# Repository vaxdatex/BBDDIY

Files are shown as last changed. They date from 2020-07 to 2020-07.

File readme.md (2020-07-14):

As Erica Synths discontinues its legacy DIY eurorack projects, we decided to make them open-source. We created Gerber files for PCB-made front panels and did slight changes in a module design in order to get rid of custom and rare components, still some modules require rare ICs which are available on www.ericasynths.lv. Each folder contains complete information and files to build a module: schematics, Gerber files for a front panel, Gerber files for PCBs, BOMs, component placement with values and designators and assembly manuals (please, note that some manuals are designed for older module versions). By making these projects opensource, Erica Synths is ok, if the third parties use them for personal, educational or commercial purposes. Erica Synths will not provide any support for these projects, please, refer to forums (www.muffwiggler.com) for information on build nuances, troubleshooting, part availability or alternatives.

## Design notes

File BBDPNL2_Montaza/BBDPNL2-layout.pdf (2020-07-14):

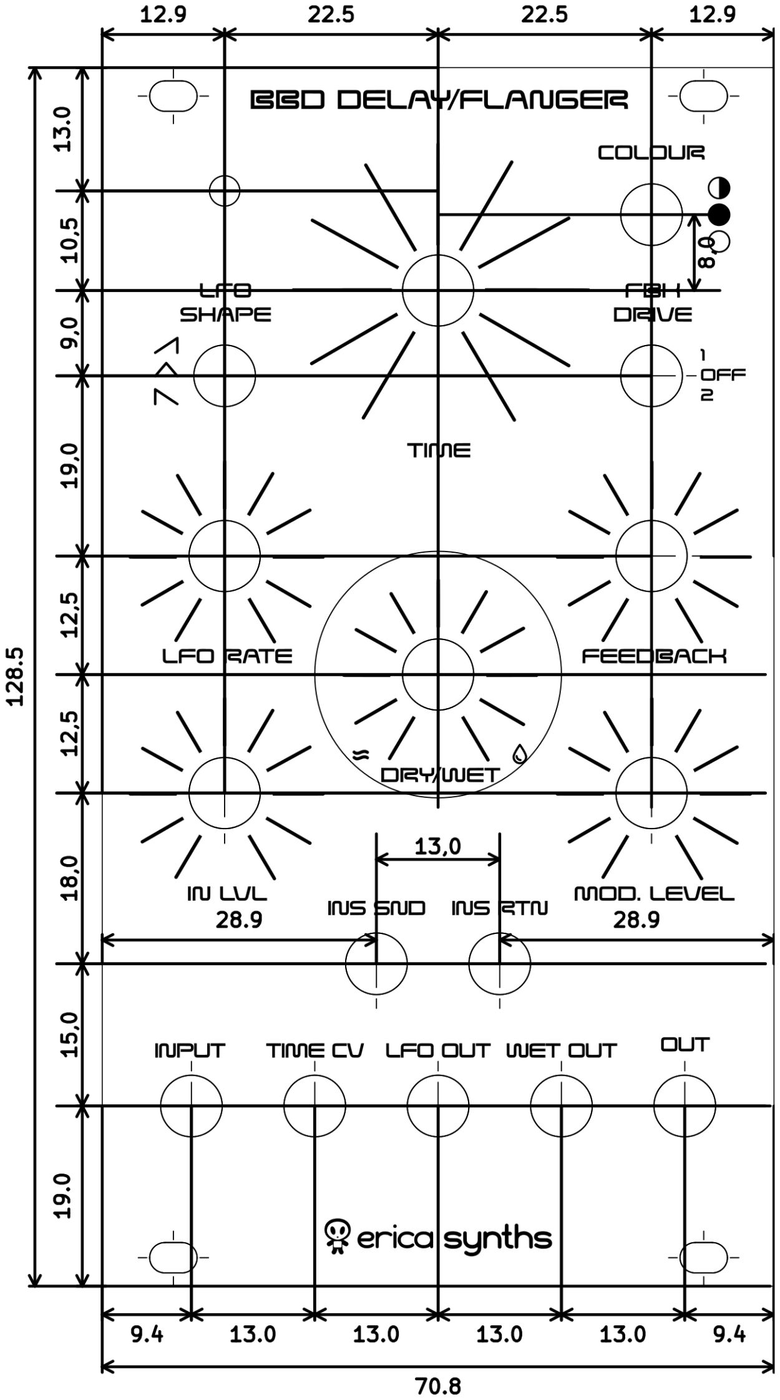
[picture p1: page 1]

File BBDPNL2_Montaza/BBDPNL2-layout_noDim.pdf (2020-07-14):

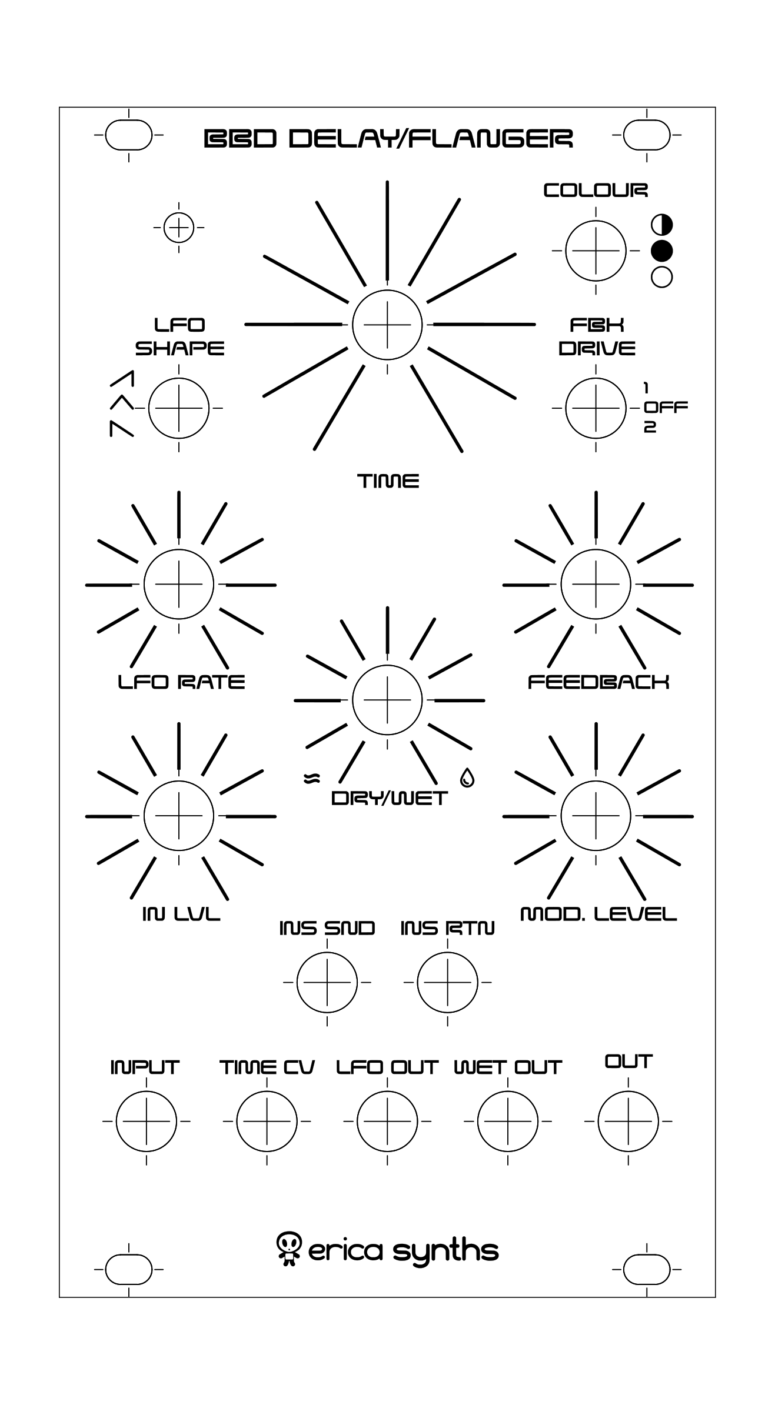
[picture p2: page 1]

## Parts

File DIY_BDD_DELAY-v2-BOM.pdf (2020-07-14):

Id Designator | Package | Quantity Designation | Supplier and ref
1 C7,C8,C11,C14,C16,C23,C25,C31,C35 | C-5mm | 9 | 0.1uF
2 C12 | CE63x25 | 1 | 10uFx25V
3 DA2 | DIP-14 | 1 | TL074
4 DA4 | DIP-14 | 1 | CD4011BE
5 DA5 | TO-92 | 1 | LM317L
6 DD1 | DIP-14 | 1 | V3205SD/MN3205 | comes with a kit
7 DD2 | DIP-8 | 1 | V3102/MN3102 | comes with a kit
8 R7 | RKT6V | 1 | 10k | single turn trimpot
9 R8 | RKT6V | 1 | 100k | single turn trimpot
10 VT1,VT2 | TO-92-M | 2 | 2N3904
11 C15 | CE63x25 | 1 | 22uFx25V
12 C19 | C-5mm | 1 | 2.2nF
13 C20,C34 | C-5mm | 2 | 1.0nF
14 C21,C29,C30 | CE63x25 | 3 | 3.3uFx16V
15 C36 | C-5mm | 1 | 220pF
16 C37 | C-5mm | 1 | 47pF
17 VD22,VD23,VD24,VD29,VD30 | DO-35 | 5 | 1N4148
18 XP2,XP3 | PLS-10 | 2 | PLS-10_MALE | comes with a kit
19 R10 | R_W4_THT | 1 | 3.9k
20 R11,R21,R39,R42,R49 | R_W4_THT | 5 | 100k
21 R13 | R_W4_THT | 1 | 8.2k
22 R14,R38,R41,R70 | R_W4_THT | 4 | 5.6k
23 R15,R16,R22 | R_W4_THT | 3 | 15k
24 R17 | R_W4_THT | 1 | 1k
25 R18 | R_W4_THT | 1 | 22k
26 R47,R66,R75,R77 | R_W4_THT | 4 | 3.3k
27 R48,R51,R55,R58,R65 | R_W4_THT | 5 | 33k
28 R54,R61,R76 | R_W4_THT | 3 | 56k
29 R62 | R_W4_THT | 1 | 2.2k
30 R63,R64 | R_W4_THT | 2 | NU | not used
31 R69 | R_W4_THT | 1 | 560ohm
31 DA1, DA4, DD1 | DIP-14 | 3 | DIP-14 Socket
31 DD2 | DIP-8 | 1 | DIP-8 Socket
PCB: DIYBBD1M

Erica Synths DIY BBD DELAY Main Board
v2.0 Sept. 2018

Id Designator | Package | Quantity Designation | Supplier and ref
1 C1,C2 | CE63x25 | 2 | 47uFx25V
2 C3,C4,C5,C6,C9,C10 | C-5mm | 6 | 0.1uF
3 DA1 | DIP-14 | 1 | TL074
4 DA3 | DIP-8 | 1 | TL072
5 L1,L2 | R0125W | 2 | 100uH | ferrite bead
6 R1,R3,R4,R6 | RD901F | 4 | B100k | Alpha potentiometer
7 R5 | RD901F | 1 | A100k | Alpha potentiometer
8 R2 | RD901F | 1 | B250k | Alpha potentiometer
9 SW1,SW2 | 2MSxT1B5M2RE | 2 | 2MS3T1B5M2RE | SPDT On-Off-On switch (https://www.thonk.co.uk/shop/sub-mini-toggle-switches/)
10 VD1 | LED-3MM | 1 | LED-3mm | Yellow LED
11 VD7,VD10 | LED-3MM | 2 | LED-3mm | Red LED
12 VD2,VD3 | DO-41 | 2 | 1N4001
14 VR1,VR2 | RB090-30 | 2 | ERF-RB-090-30 | Resettable fuse
15 VT3 | TO-92-M | 1 | 2N3904
16 XP1 | IDC-10MS | 1 | IDC-10MS
17 XS1,XS2,XS3,XS4,XS5,XS6,XS7 | WQP-PJ301M-12 | 7 | 3,5mm mono jacks | Thonkiconn jacks (https://www.thonk.co.uk/shop/3-5mm-jacks/)
18 C17,C18,C32,C33,C13 | CE63x25_NP | 5 | 10uFx25V | non polarized
19 C22 | C-5mm | 1 | 22nF
20 C24 | C-5mm | 1 | 10nF
21 C26 | C-5mm | 1 | 5.6nF
22 C27 | C-5mm | 1 | 680pF
23 C28 | C-5mm | 1 | 220pF

24

VD4,VD5,VD6,VD8,VD9,VD11,VD12,VD13,VD1
4, VD15,VD16,VD17,VD18,VD19,VD20, VD21,VD25,VD26,VD27,VD28 | DO-35 | 20 | 1N4148
25 SW3 | 2MDxT1B5M2RE | 1 | 2MD3T1B5M2RE | DPDT On-Off-On Switch (https://www.thonk.co.uk/shop/sub-mini-toggle-switches/)
26 XS8,XS9 | PBS-10 | 2 | PBS-10_FEMALE | comes with a kit
27 R9,R23,R28,R29,R30,R33,R34,R67,R68 | R_W4_THT | 9 | 100k
28 R12,R20,R32,R35,R40,R52,R59,R60,R72 | R_W4_THT | 10 | 10k
29 R19,R37,R44,R50,R56,R57,R71 | R_W4_THT | 7 | NU | not used
30 R24 | R_W4_THT | 1 | 56k
31 R25,R43,R45,R46,R53,R78,R79 | R_W4_THT | 7 | 33k
32 R26,R27,R36,R73,R74 | R_W4_THT | 5 | 470ohm
33 R31 | R_W4_THT | 1 | 4.7k
34 DA1 | DIP-14 | 1 | DIP-14 Socket
35 DA3 | DIP-8 | 1 | DIP-8 Socket
PCB: DIYBBD1C

Mouser shopping cart (excludes jacks, switches and potentiometers) (https://www.mouser.com/ProjectManager/ProjectDetail.aspx?AccessID=d779a12717)

Erica Synths DIY BBD DELAY Controls Board
v2.0 Sept. 2018

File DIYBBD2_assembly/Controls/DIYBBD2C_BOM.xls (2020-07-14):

 | Erica Synths DIY BBD DELAY v2.0 Sept. 2018
Id | Designator | Package | Quantity | Designation | Supplier and ref
1 | C1,C2 | CE63x25 | 2 | 47uFx25V
2 | C3,C4,C5,C6,C9,C10 | C-5mm | 6 | 0.1uF
3 | DA1 | DIP-14_Socket | 1 | TL074
4 | DA3 | DIP-8_Socket | 1 | TL072
5 | L1,L2 | R0125W | 2 | 100uH
6 | R1,R3,R4,R6 | RD901F | 4 | B100k | Thonk, Tayda
7 | R2 | RD901F | 1 | B250k | Thonk, Tayda
8 | SW1,SW2 | 2MSxT1B5M2RE | 2 | 2MS3T1B5M2RE | Farnell
9 | VD1 | LED-3MM | 1 | LED-3mm
10 | VD2,VD3 | DO-41 | 2 | 1N4001
11 | VD4,VD5 | DO-35 | 2 | *
12 | VR1,VR2 | RB090-30 | 2 | ERF-RB-090-30
13 | VT3 | TO-92-M | 1 | 2N3904
14 | XP1 | IDC-10MS | 1 | IDC-10MS
15 | XS1,XS2,XS3,XS4,XS5,XS6,XS7 | WQP-PJ301M-12 | 7 | WQP-PJ301M-12 | Thonk
16 | C17,C18,C32,C33,C13 | CE63x25_NP | 5 | 10uFx25V
17 | C22 | C-5mm | 1 | 22nF
18 | C24 | C-5mm | 1 | 10nF
19 | C26 | C-5mm | 1 | 5.6nF
20 | C27 | C-5mm | 1 | 680pF
21 | C28 | C-5mm | 1 | 220pF
22 | VD6,VD8,VD9,VD11,VD12,VD13,VD14,VD15,VD16,VD17,VD18,VD19,VD20,VD21,VD25,VD26,VD27,VD28 | DO-35 | 18 | 1N4148
23 | VD7,VD10 | LED-3MM | 2 | NU
24 | R5 | RD901F | 1 | A100k | Thonk, Tayda
25 | SW3 | 2MDxT1B5M2RE | 1 | 2MD3T1B5M2RE | Farnell
26 | XS8,XS9 | PBS-10 | 2 | PBS-10_FEMALE
27 | R9,R23,R28,R29,R30,R33,R34,R67,R68 | R_W4_THT | 9 | 100k
28 | R12,R20,R32,R35,R40,R52,R59,R60,R72 | R_W4_THT | 9 | 10k
29 | R19,R37,R44,R50,R56,R57 | R_W4_THT | 6 | NU
30 | R24 | R_W4_THT | 1 | 56k
31 | R25,R43,R45,R46,R53,R78,R79 | R_W4_THT | 7 | 33k
32 | R26,R27,R36,R73,R74 | R_W4_THT | 5 | 470
33 | R31 | R_W4_THT | 1 | 4.7k
34 | R71 | R_W4_THT | 1 | Drive Gain
 | PCB: DIYBBD2C

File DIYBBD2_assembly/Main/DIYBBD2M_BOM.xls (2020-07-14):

 | Erica Synths DIY BBD DELAY v2.0 Sept. 2018
Id | Designator | Package | Quantity | Designation | Supplier and ref
1 | C7,C8,C11,C14,C16,C23,C25,C31,C35 | C-5mm | 9 | 0.1uF
2 | C12 | CE63x25 | 1 | 10uFx25V
3 | DA2 | DIP-14_Socket | 1 | TL074
4 | DA4 | DIP-14_Socket | 1 | CD4011BE
5 | DA5 | TO-92 | 1 | LM317L
6 | DD2 | DIP-8_Socket | 1 | V3102/MN3102 | ebay
7 | R7 | RKT6V | 1 | B10k
8 | R8 | RKT6V | 1 | 100k
9 | VT1,VT2 | TO-92-M | 2 | 2N3904
10 | C15 | CE63x25 | 1 | 22uFx25V
11 | C19 | C-5mm | 1 | 2.2nF
12 | C20,C34 | C-5mm | 2 | 1.0nF
13 | C21,C29,C30 | CE63x25 | 3 | 3.3uFx16V
14 | C36 | C-5mm | 1 | 220pF
15 | C37 | C-5mm | 1 | 47pF
16 | VD22,VD23,VD24,VD29,VD30 | DO-35 | 5 | 1N4148
17 | XP2,XP3 | PLS-10 | 2 | PLS-10_MALE
18 | R10 | R_W4_THT | 1 | 3.9k
19 | R11,R21,R39,R42,R49 | R_W4_THT | 5 | 100k
20 | R13 | R_W4_THT | 1 | 8.2k
21 | R14,R38,R41,R70 | R_W4_THT | 4 | 5.6k
22 | R15,R16,R22 | R_W4_THT | 3 | 15k
23 | R17 | R_W4_THT | 1 | 1k
24 | R18 | R_W4_THT | 1 | 22k
25 | R47,R66,R75,R77 | R_W4_THT | 4 | 3.3k
26 | R48,R51,R55,R58,R65 | R_W4_THT | 5 | 33k
27 | R54,R61,R76 | R_W4_THT | 3 | 56k
28 | R62 | R_W4_THT | 1 | 2.2k
29 | R63,R64 | R_W4_THT | 2 | NU
30 | R69 | R_W4_THT | 1 | 560
31 | DD1 | DIP-14_Socket_V3205 | 1 | V3205SD/MN3205 | ebay
 | PCB: DIYBBD2M

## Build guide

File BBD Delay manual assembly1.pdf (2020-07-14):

## GUIDE TO ASSEMBLY OF ERICA SYNTHS DIY BBD DELAY/FLANGER

If you are reading this, most probably, you are about to build Erica Synths DIY BBD DELAY/FLANGER module. The module is 14HP wide, 45mm deep, skiff friendly, has solid mechanical construction and doesn’t require wiring.
Erica Synths DIY BBD Delay /FLANGER is one of few BBD (bucket brigade delay) chips based DIY modules. The module is designed to provide variety of effects from flanger to delays with adjustable flavours and plenty of modulation possibilities. It has built in LFO with selectable shape and dedicated LFO output, delay time CV input with an attenuator, selectable feedback overdrive and feedback Send-Return connectors, so you can apply external effects on feedback signal. Maximums feedback settings put the module in self oscillation, so it can be used as an experimental sound source, as well.

The DIY kit comes in three versions:
1) Set of 2 PCBs + BBD ICs (V3205 and V3102),
2) Set of 2 PCBs + BBD ICs + mechanical parts (PCB connectors and spacer)+ panel,
3) Full kit.

FEATURES:
- 4092 stage BBD
- Up to 300ms delay time
- Delay time CV input with an attenuator
- Feedback Send-Return circuit for external effects
- Built in LFO with dedicated output
- Two customizable feedback overdrive flavours
- LP filter on the output with selectable cutoff
- Dedicated Wet output

SPECIFICATIONS:
- Max Delay time | 300ms
- Audio output amplitude | 10Vptp
- CV amplitude (full span) | -5V - +5V
- Panel width | 14HP
- Module depth | 45mm
- Power consumption | 30mA @+12V,
| 20mA@-12V

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
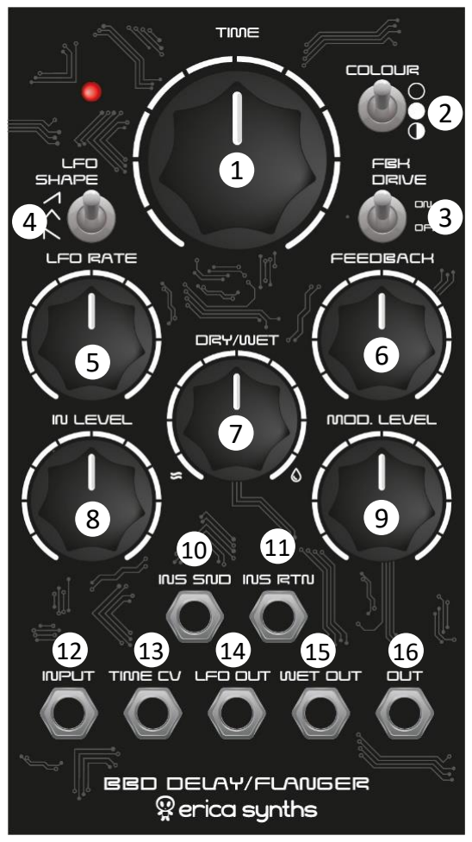
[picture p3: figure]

The big knob sets delay time from 0 CCW to 300ms CW.
The COLOUR switch applies the LP filter of two selectable cutoff frequencies on the output. Mid position means – no filter applied, top position is “Darker”, bottom position “Dark”. Use the filter with low frequency audio on the input!
Select one of two feedback signal overdrive flavours

Adjust feedback level! In full CW setting the module will go to self oscillation
This is the Dry/Wet crossfade control
Adjust the audio input level! DDB Delays are sensitive to the audio input level, so experiment with settings to get different results!

9

This is the delay time CV attenuator. It’s internally patched to built in LFO, but when you patch a external modulation signal, the internal connection is replaced by the external one
10 This is the feedback FX Send output, meaning, you can break the feedback path and send the feedback signal to external modifiers, multimode filter, for example
11 This is the feedback FX return input. Patch the modified signal back here!
12 This is the audio signal input. Adjust the signal level for various effect flavours!
13
14

15

Select the built in LFO shape
Adjust the built in LFO frequency. The LFO is internally routed to the delay time CV through the MOD LEVEL attenuator. The LED will give visual feedback on the LFO rate.

This is the wet signal output. Here you have another audio signal to build some interesting patches
This is the output of the module. We believe, you’ll enjoy results!

16

This is the LFO output. You can use the built in LFO to modulate other modules in your rack and have interesting synced effects

This is the delay time CV input

Take precautions with regard to electrostatic discharge (ESD) safety. Handling components should be done in electrostatically safe environment. Use personal and workplace grounding. Any discharge (even a minor one) from body to a component may permanently damage it.
Our PCBs have silkscreened both component values and designators, but we highly recommend you to print out files with component placement before you start assembly of the module. And, please, at least take a look on this manual!
Some components are marked as NU (not used) – leave those unpopulated! Some components are market as OPTION (those are for optional modifications) – leave those unpopulated for now.

### ASSEMBLY

1

There are two PCBs – the Control PCB with potentiometers, switches, jack and the Main PCB with components around BBDs. Solder horizontally placed resistors, diodes and ferrite beads on both PCBs! Pay attention on orientation of diodes!

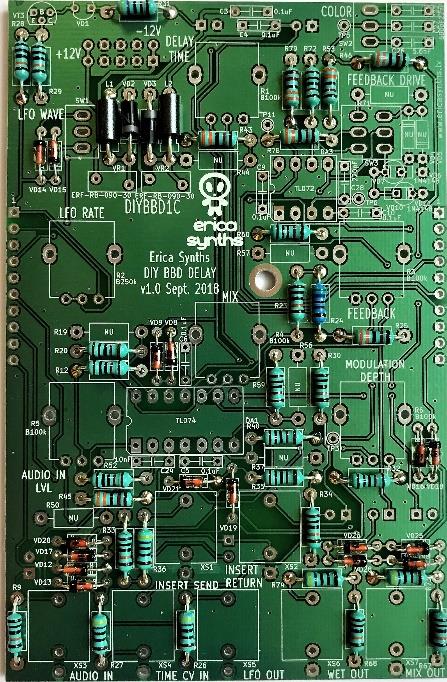
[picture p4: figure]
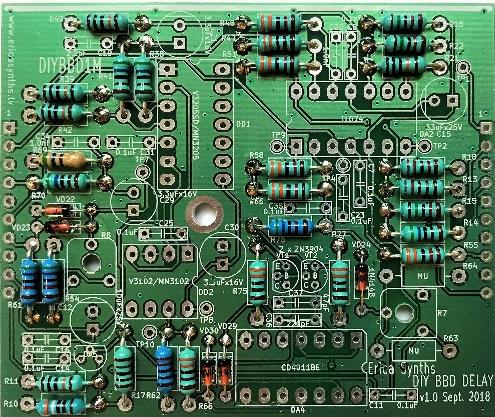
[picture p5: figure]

### 2 Solder IC sockets, and then ceramic and film capacitors on both PCBs!

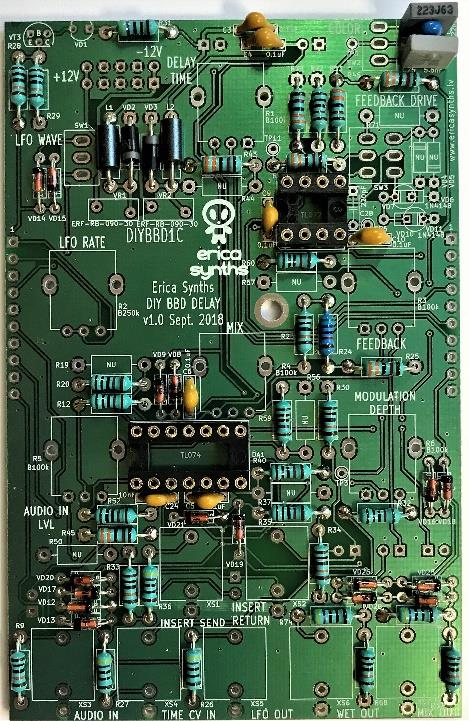
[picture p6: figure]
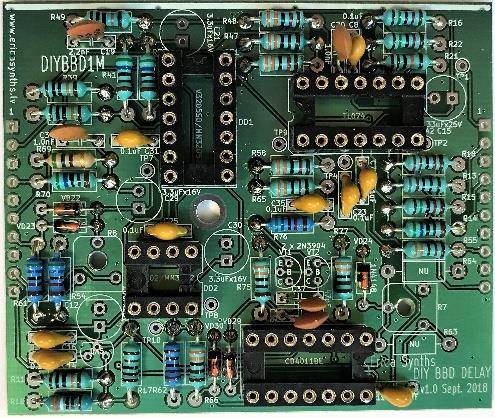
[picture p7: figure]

3 Turn the Control board around and solder electrolytic capacitors, the PSU connector and 1x10 pin female connectors! Also fix the 11mm spacer on the board. Solder transistors, electrolytic capacitors on the Main board! Pay attention on the orientation of both! Also solder the trimpots on the main board.

4

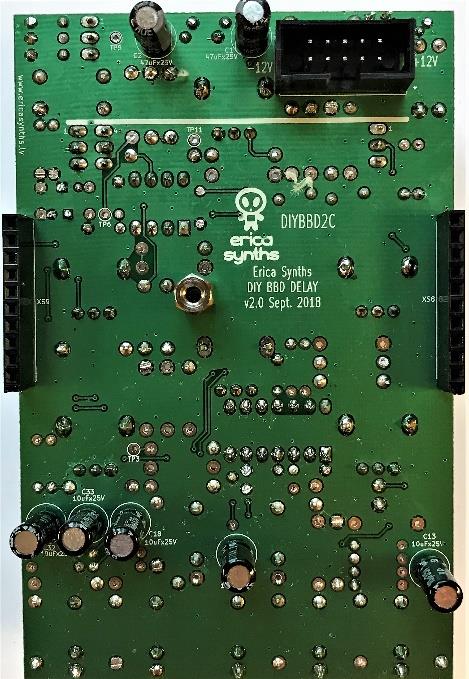
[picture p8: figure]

Solder transistor, resettable fuses, potentiometers, switches and jacks on the control board! Insert the LED, but do not solder it, yet! Switches have two nuts – remove one of them and screw other on until it’s fixed against the switch! Next to the FEEDBACK DRIVE switch you’ll find solder pads for overdrive diodes. You can use any diodes of your taste for pairs VD4/VD5 and VD6/VD11 or VD7/VD10 which are LEDs. The kit contains two red LEDs (if you use LEDs, do not populate

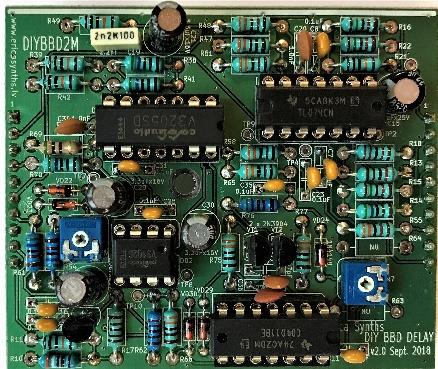
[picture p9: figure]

VD6/VD11) and 1N4148 for VD4/VD5. You may experiment here with different diodes (try germanium diodes for softer overdrive) of LEDs of various colours – it will result in different overdrive flavour. I used 33k for R71 and 100k for R72 in the overdrive configuration supplied with a kit.

5

Solder 1x10 pin male connectors on the Main board!

Negative lug of the
electrolytic
capacitor is marked
with a stripe!

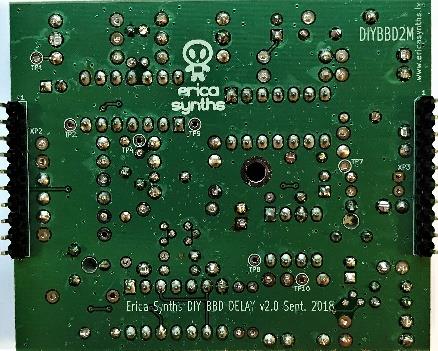
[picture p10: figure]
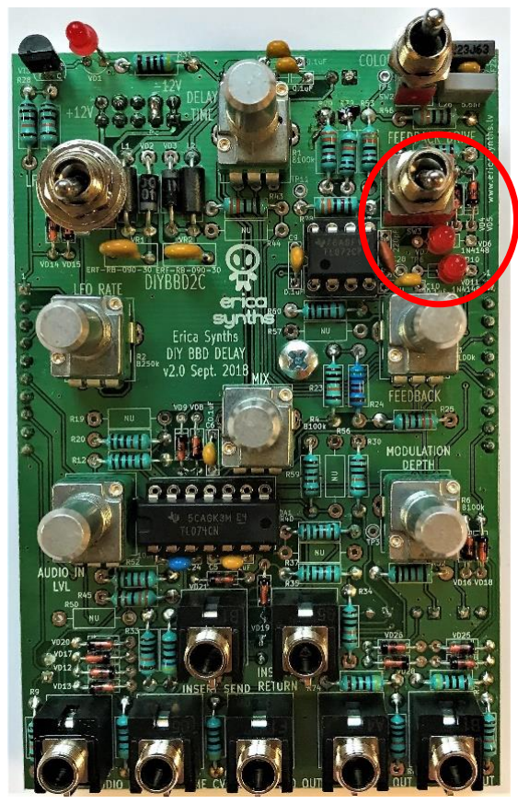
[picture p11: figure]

5

Place the panel on the Controls board fix it with couple of nuts and push the LED through the hole. Solder the LED! Remove the panel, install ICs on both boards (pay close attention to the orientation of ICs!) and connect both boards together as shown on the picture! Now you can connect the module to the PSU! Set all switches in the middle position, IN LEVEL full clockwise, Dry/Wet and MOD LEVEL full CCW, other potentiometers at 12 o’clock! Check if you get some sound from the module in the DRY setting and then fade the potentiometer to the WET setting. You should hear the wet signal, as well.

6

Now it’s time for initial calibration! There are two trimpots on the main board.
R8 is BBD offset adjustment. Connect the WET OUT to the oscilloscope or mixer with headphones and feed the sinewave in the audio INPUT and adjust the trimpot for the least distortion (you can do it just listening to the signal on WET output).
R7 stets maximum delay time. Adjust it to your taste. The longer is the delay, the noisier gets the signal, so find the compromise.

7

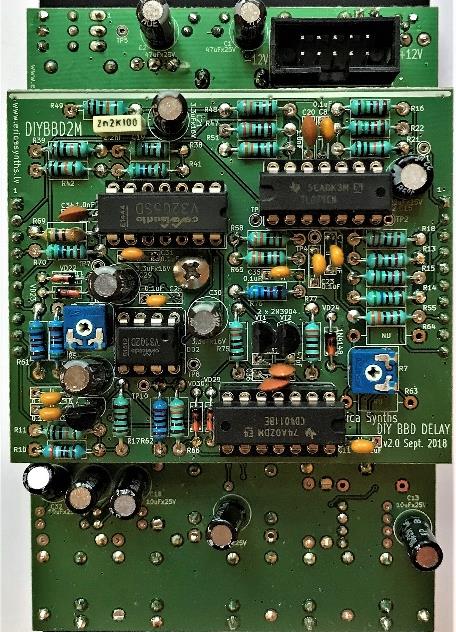
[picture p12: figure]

Now, let’s take care about feedback overdrive circuit! One side of the switch in top or bottom position connects set of overdrive diodes to the feedback circuit; other part, adjusts feedback gain, meaning, different diodes limit the signal in unique way, and you need to adjust the gain of the feedback signal, so that the module goes into self-oscillation at approximately same setting for all switch positions. R71 sets gain for VD4/VD5, R72 sets gain for LEDs. Please, note that using different diodes or LEDs than supplied with a kit may require selection of R71 and R72

8

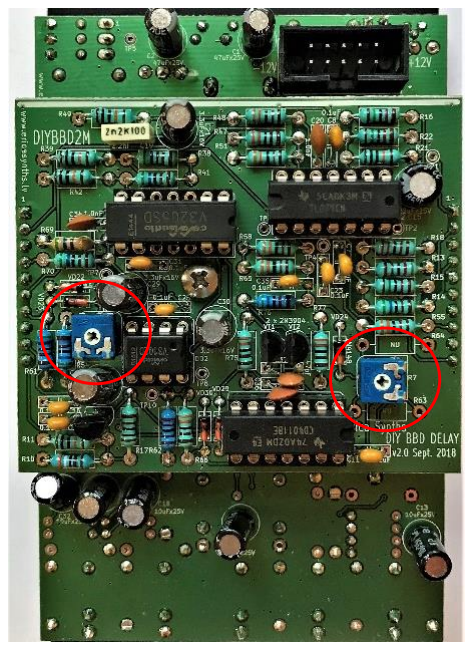
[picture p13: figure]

Now, you can install the front panel and knobs. Don’t forget to fix the Main board to the spacer, using a M3 screw.
The module is ready to use! Enjoy!

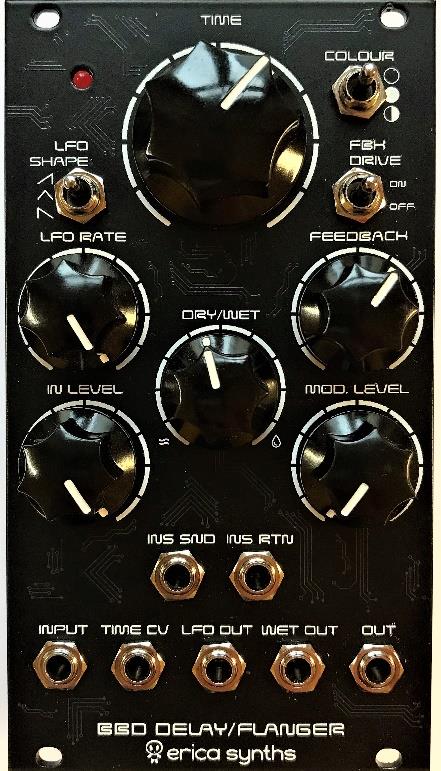
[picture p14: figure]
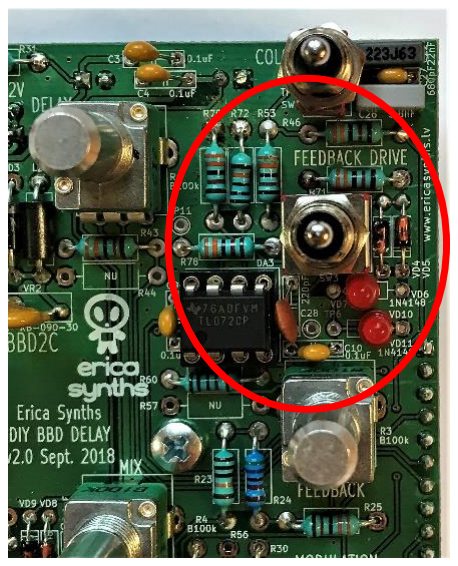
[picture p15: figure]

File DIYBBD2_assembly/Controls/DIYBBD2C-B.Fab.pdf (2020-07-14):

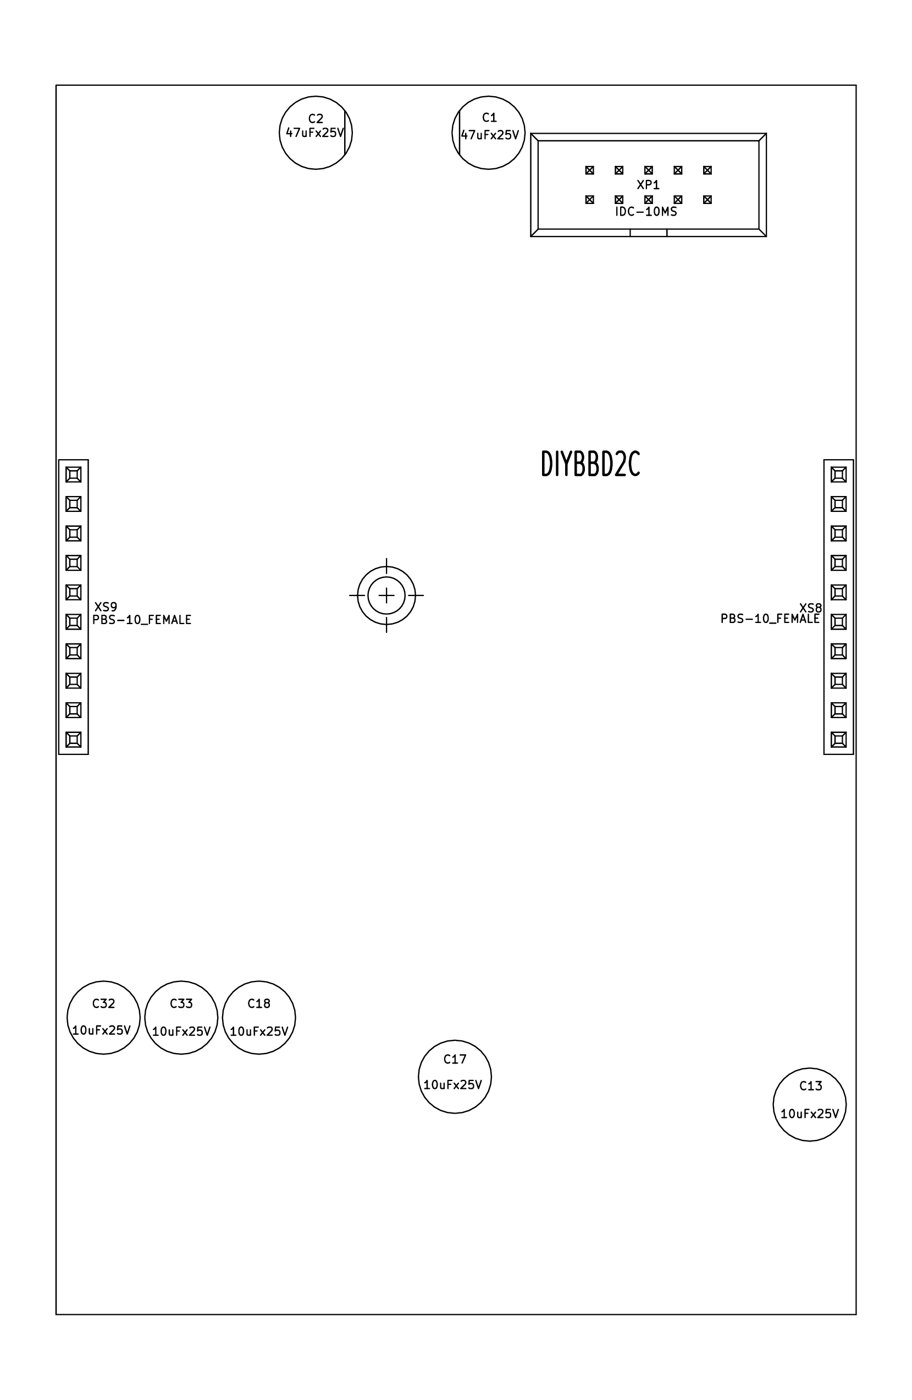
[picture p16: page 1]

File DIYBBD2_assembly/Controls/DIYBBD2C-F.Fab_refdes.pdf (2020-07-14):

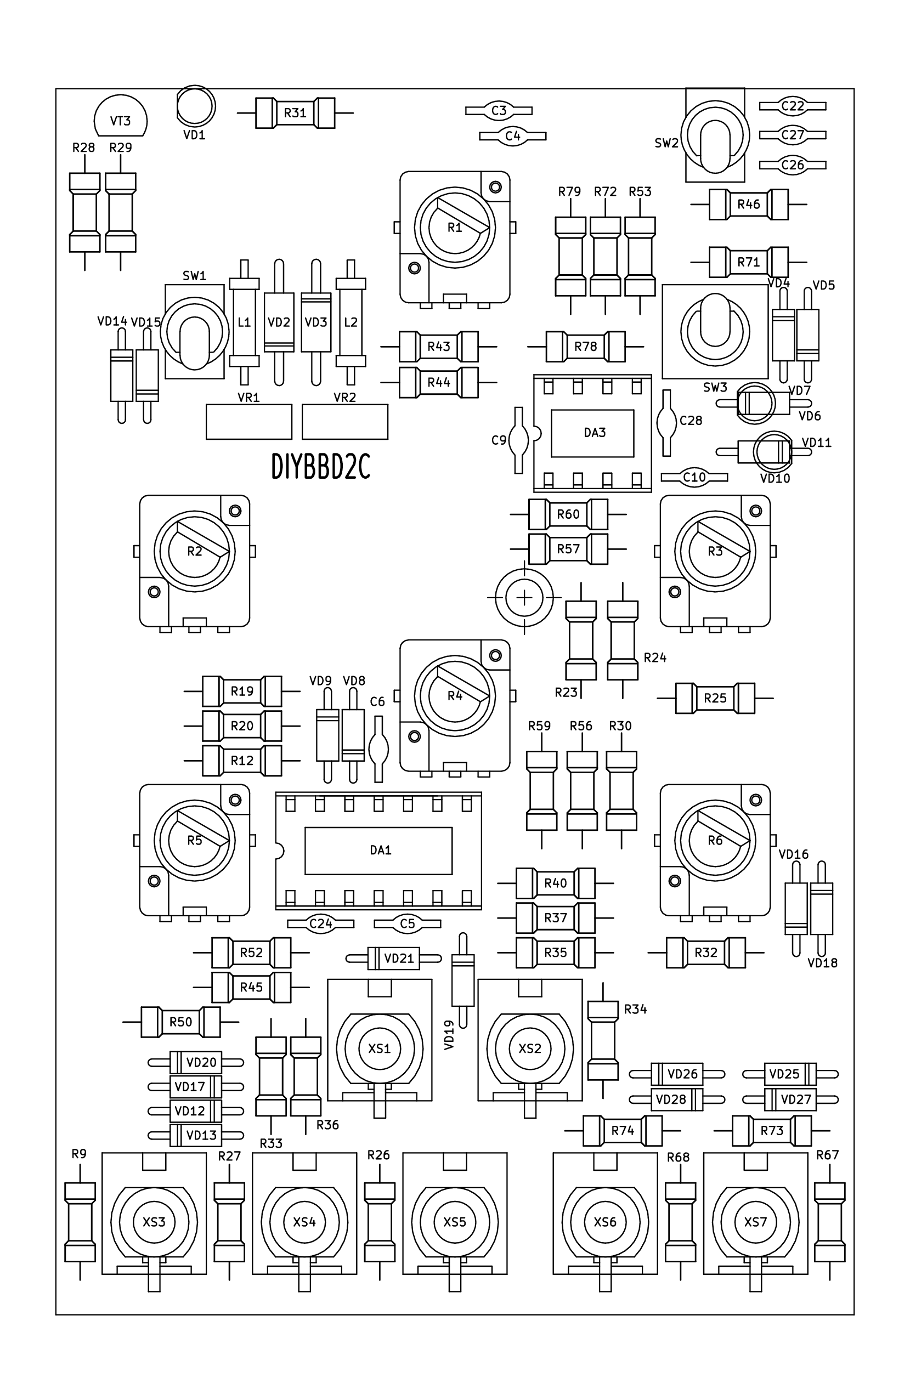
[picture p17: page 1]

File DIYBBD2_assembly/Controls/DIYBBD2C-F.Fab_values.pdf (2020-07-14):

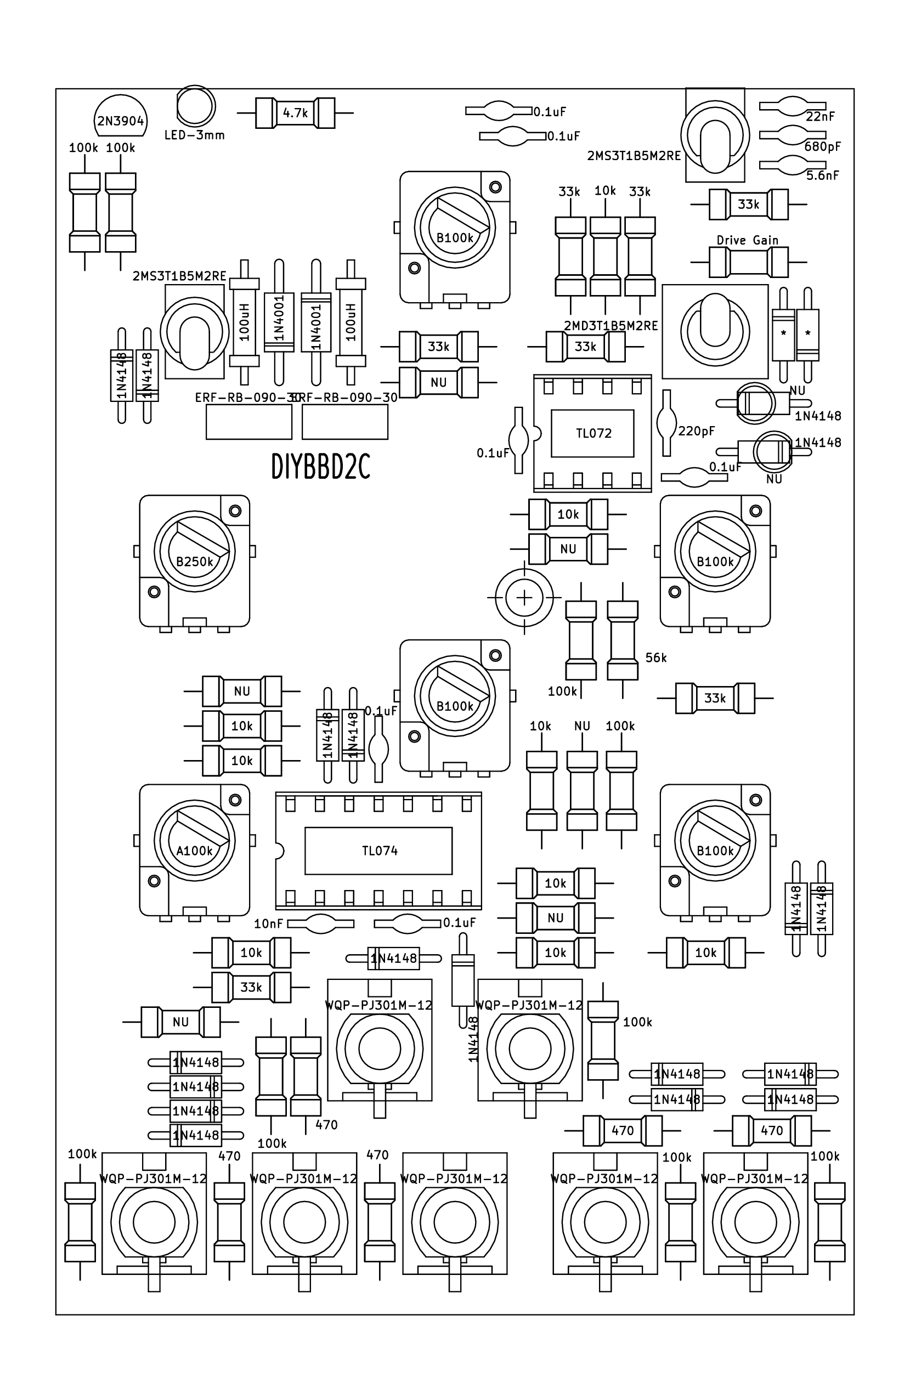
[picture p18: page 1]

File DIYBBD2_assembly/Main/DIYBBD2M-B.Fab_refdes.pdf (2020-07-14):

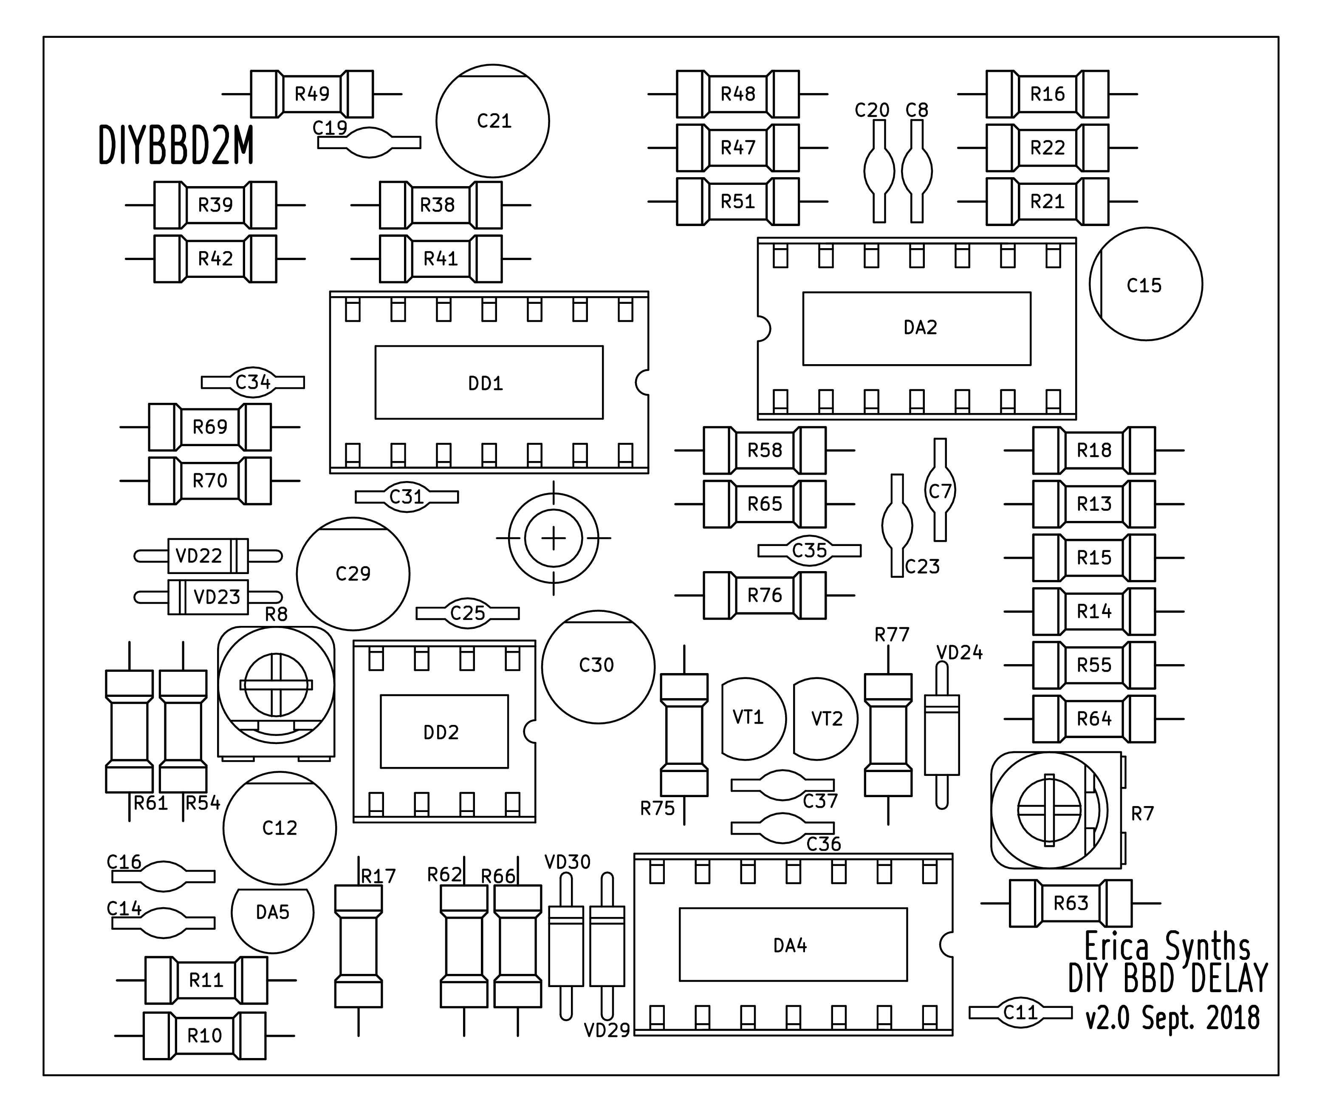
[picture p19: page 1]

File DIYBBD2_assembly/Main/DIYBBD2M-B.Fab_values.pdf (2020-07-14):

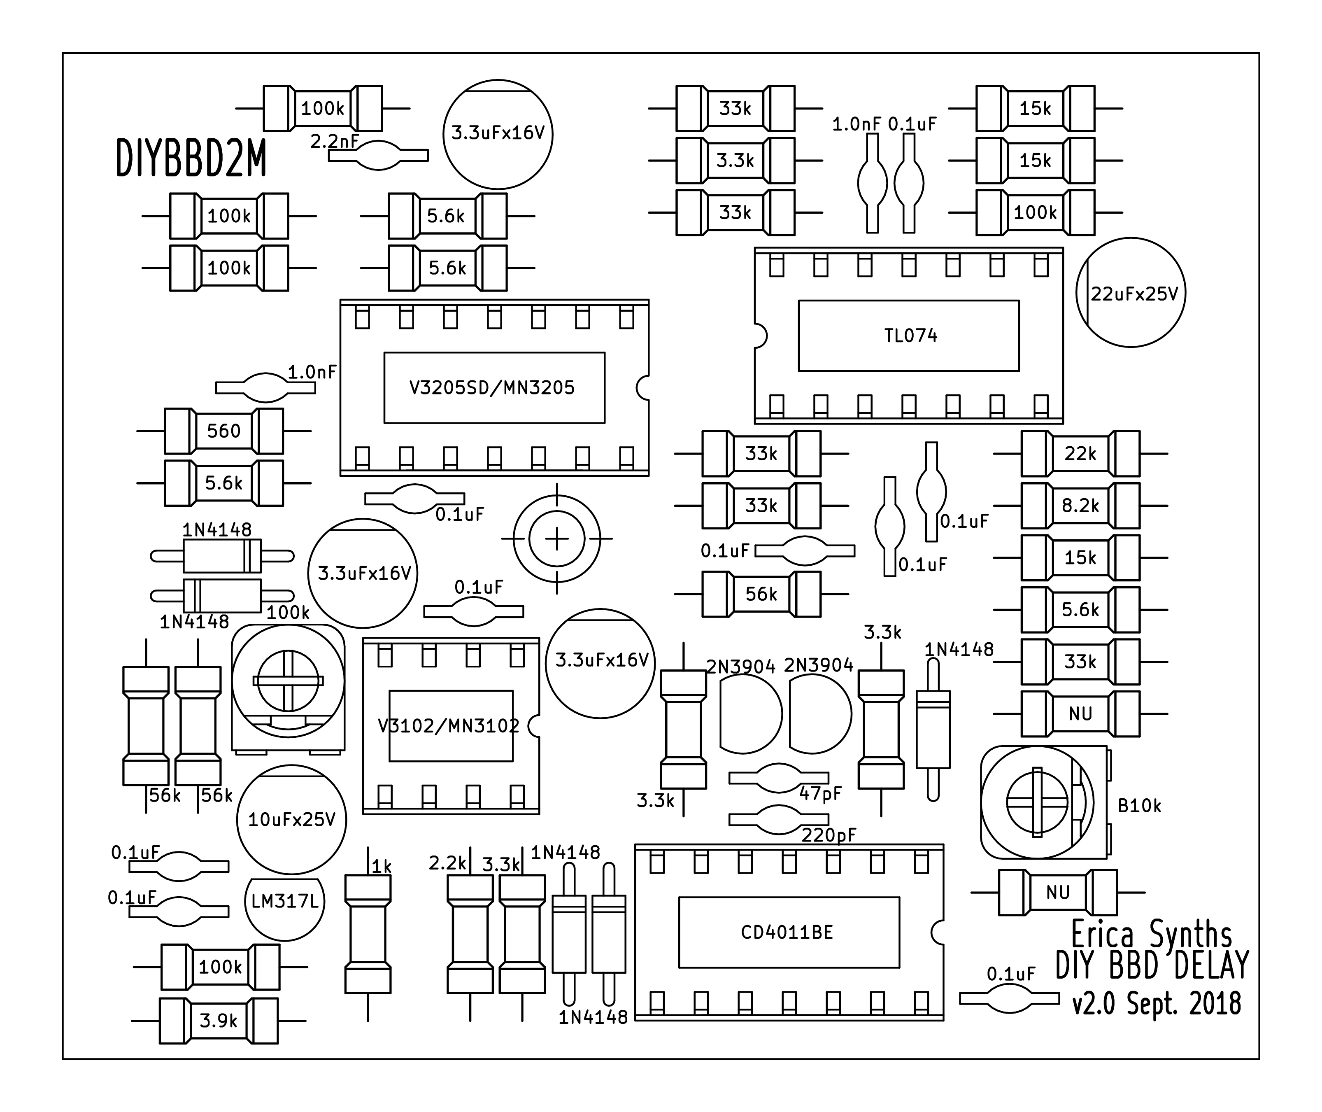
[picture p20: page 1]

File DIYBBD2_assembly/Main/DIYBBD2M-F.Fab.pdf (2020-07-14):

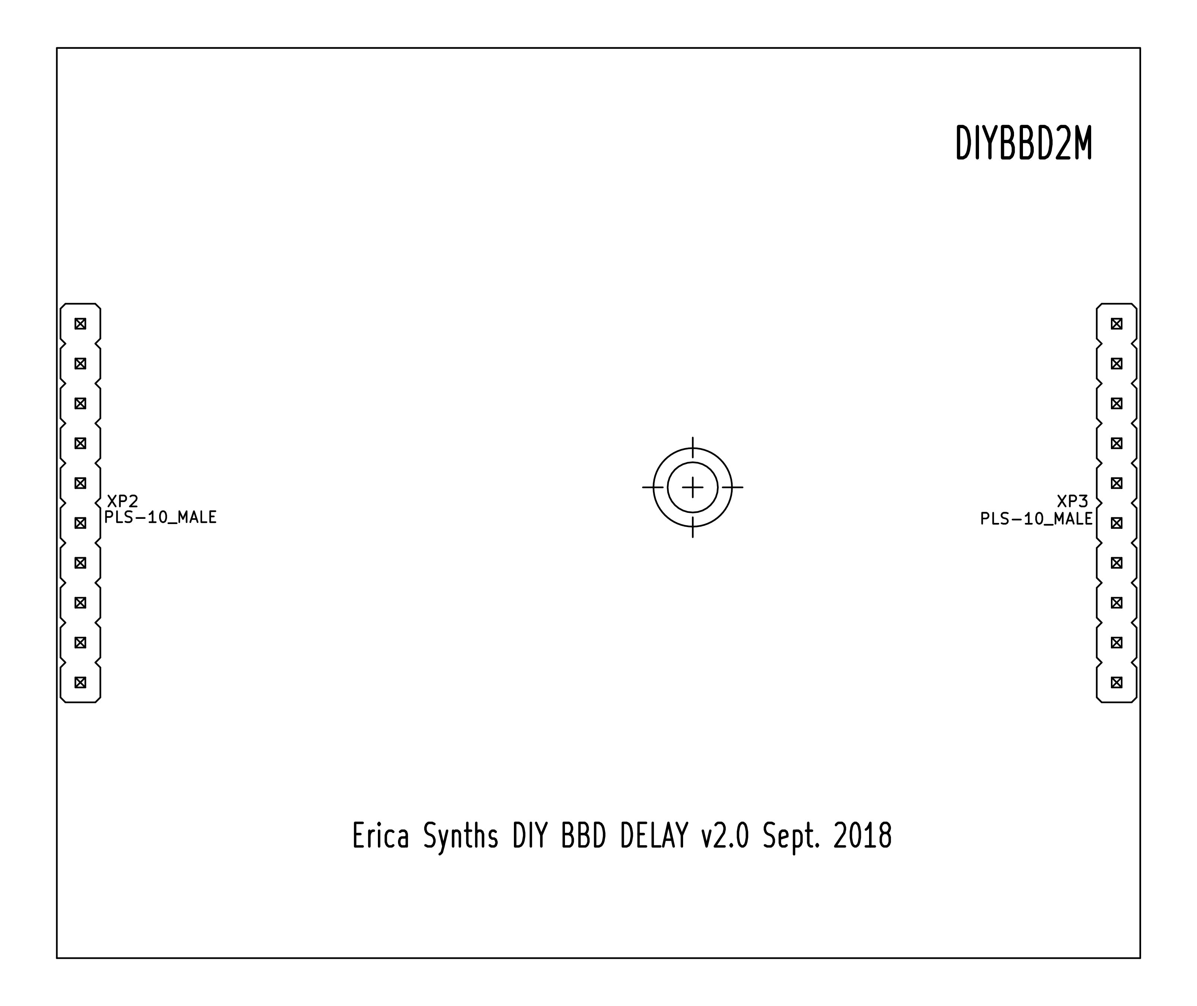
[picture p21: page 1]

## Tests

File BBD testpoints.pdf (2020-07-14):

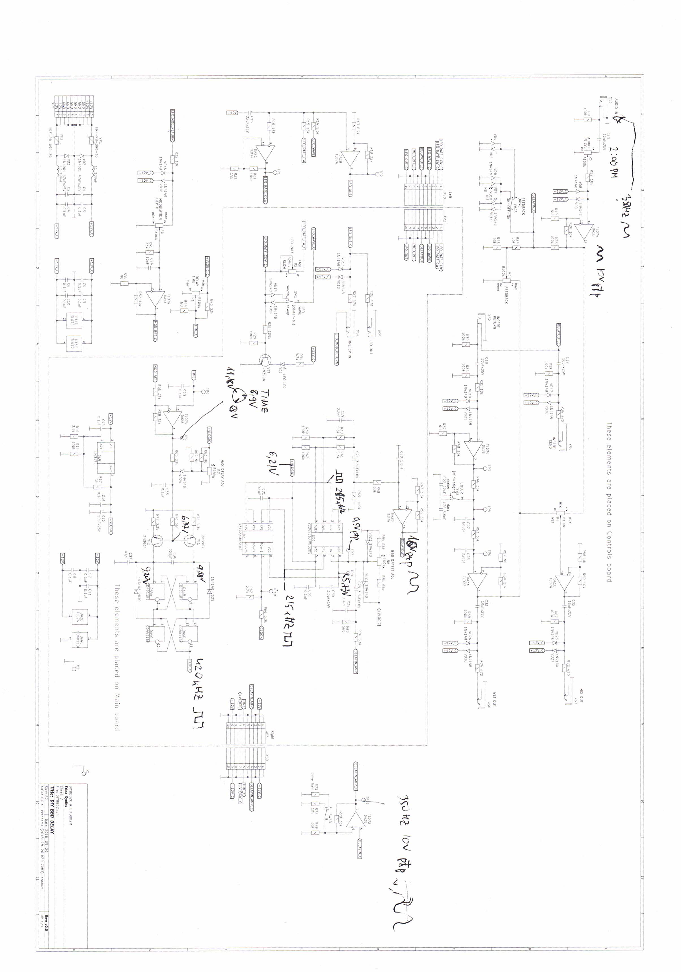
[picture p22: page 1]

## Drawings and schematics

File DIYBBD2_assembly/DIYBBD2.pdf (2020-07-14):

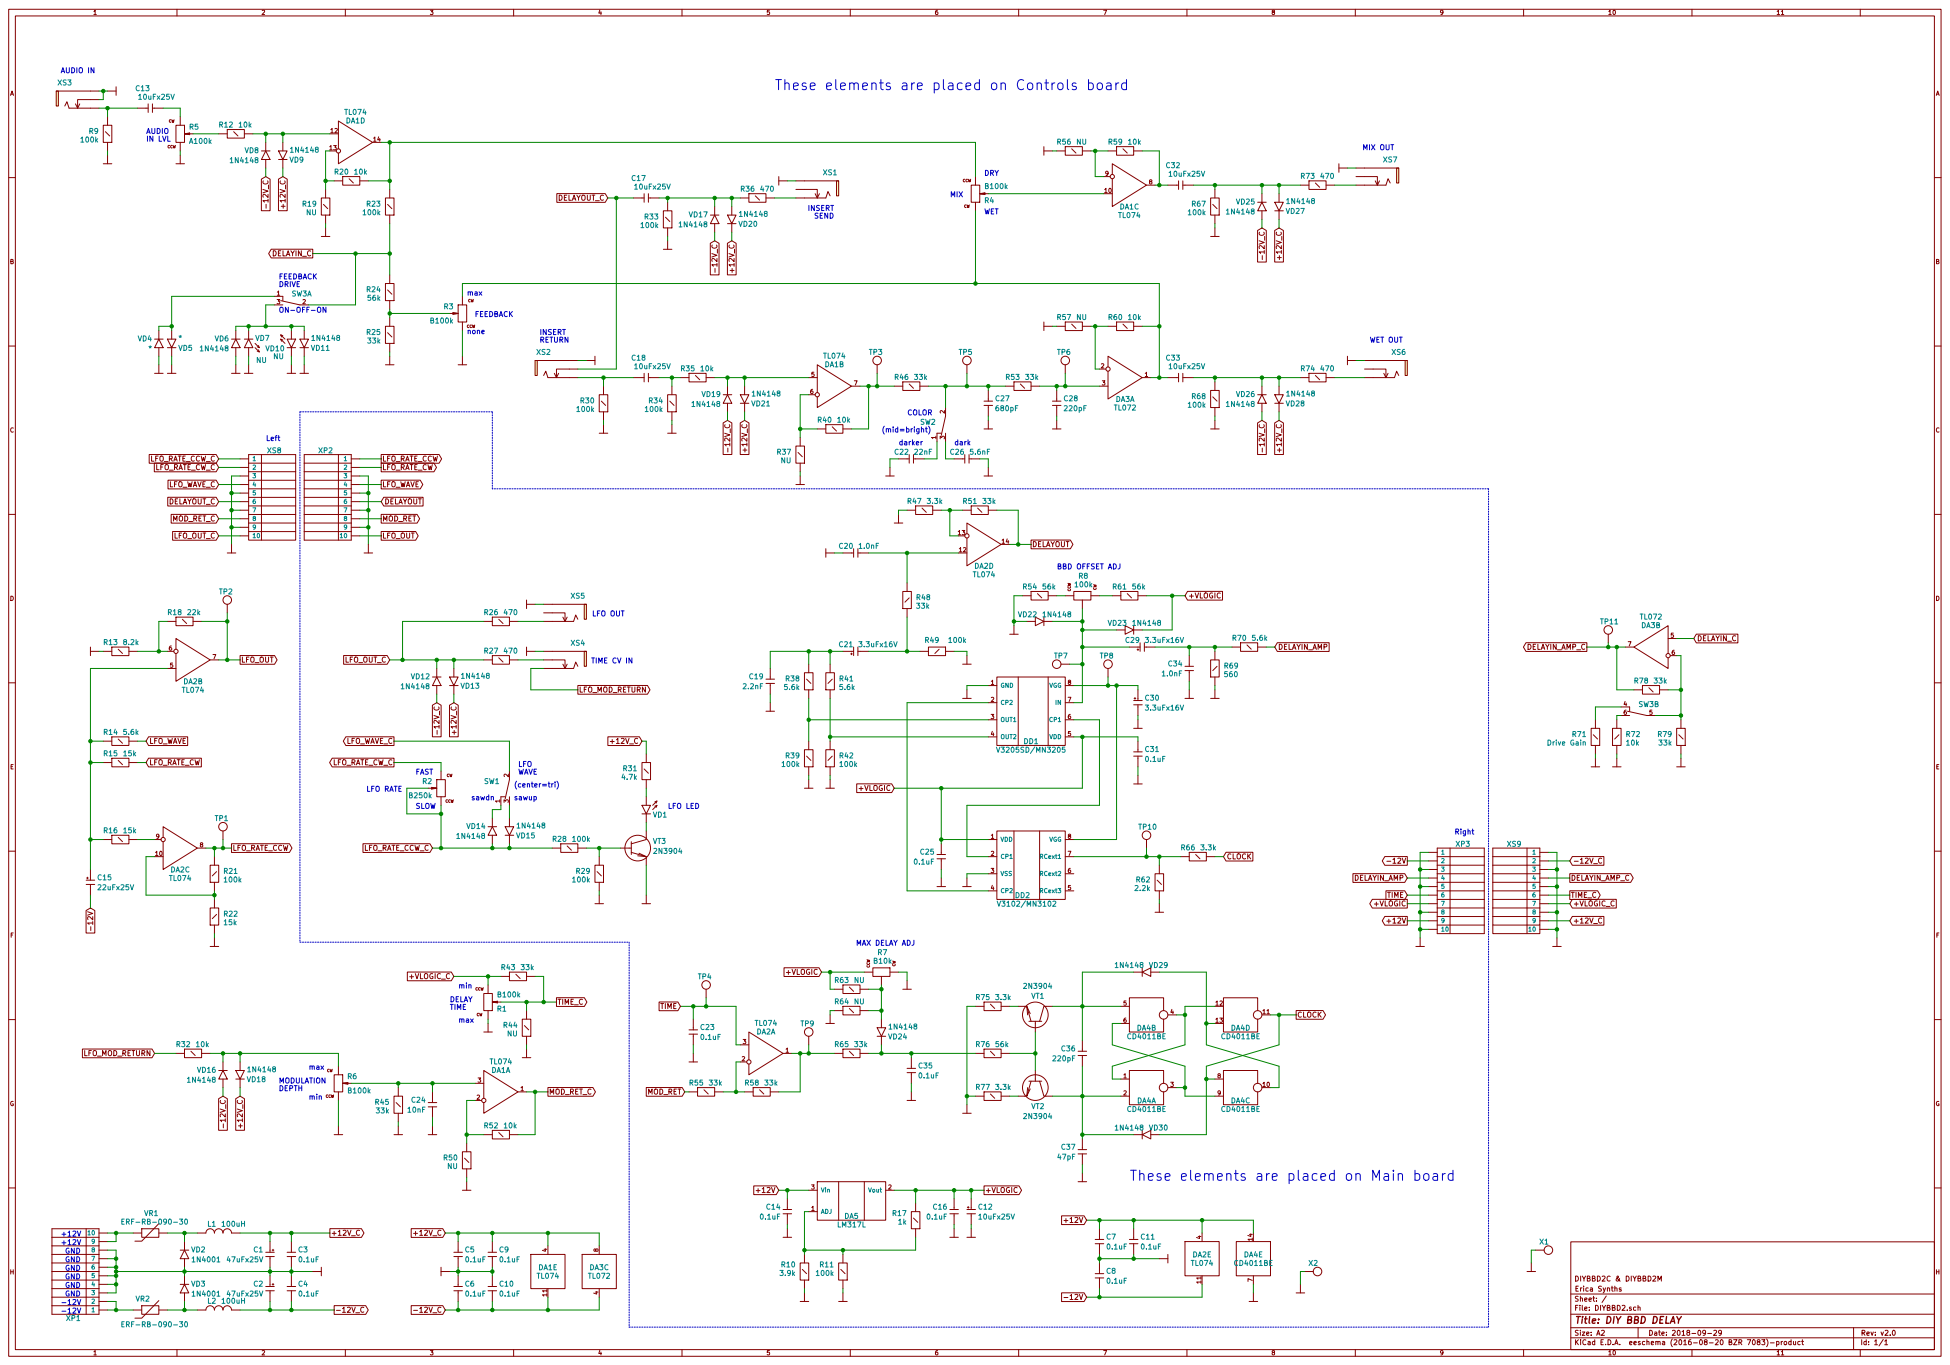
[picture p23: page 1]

These elements are placed on Controls board

These elements are placed on Main board

GND | 10 XP1 +12V 7
+12V GND | 9

GND | 6
GND | 5
GND | 4
GND | 3
-12V | 2
-12V | 1

File: DIYBBD2.sch Sheet: / Erica Synths DIYBBD2C & DIYBBD2M

Id: 1/1 Title: DIY BBD DELAY
